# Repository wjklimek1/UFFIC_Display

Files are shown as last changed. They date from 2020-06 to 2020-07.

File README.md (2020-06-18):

# UFFIC_Display
Ultra Fast Inter Integrated Circuit Display

UFIIC Display converts I2C serial data to HD44780 display commands. It can be powered from 3.3V or 5V power source. In case of using 3.3V power source internal step-up converter is used to boost voltage to 5V required to power HD44780 itself. Converter is based on cheap STM32F030F4P6 microcontroller that can be programmed and debuged via SWD interface.

Project is at early stage of development now, code for UFIIC and Arduino library will be provided in the future.

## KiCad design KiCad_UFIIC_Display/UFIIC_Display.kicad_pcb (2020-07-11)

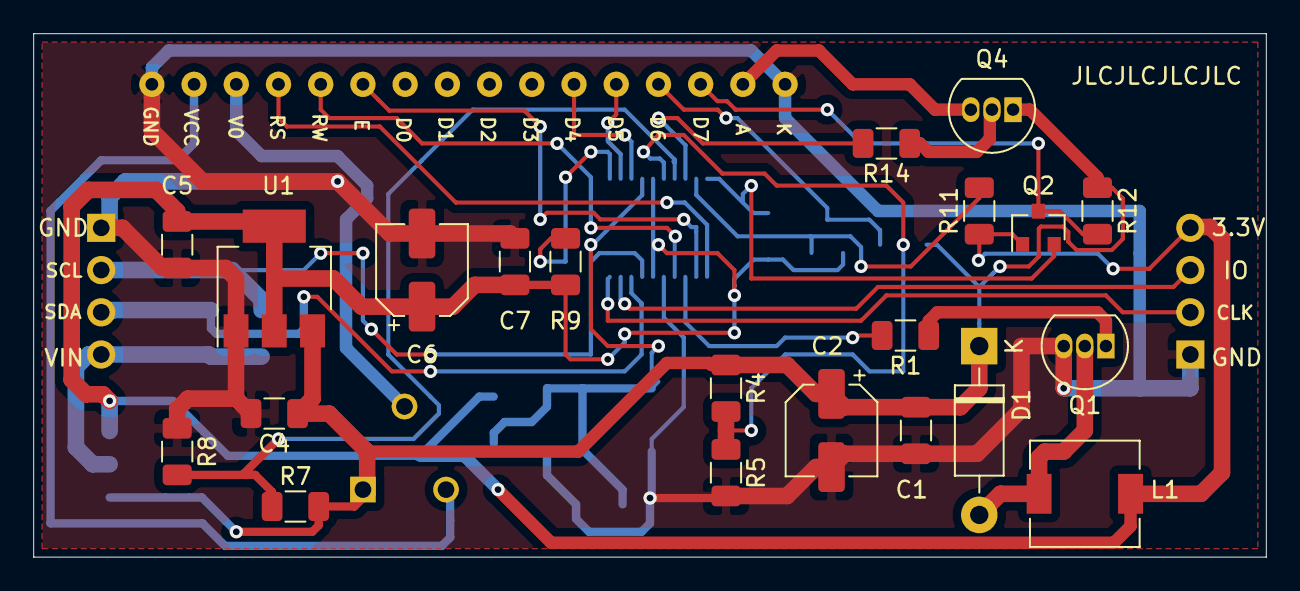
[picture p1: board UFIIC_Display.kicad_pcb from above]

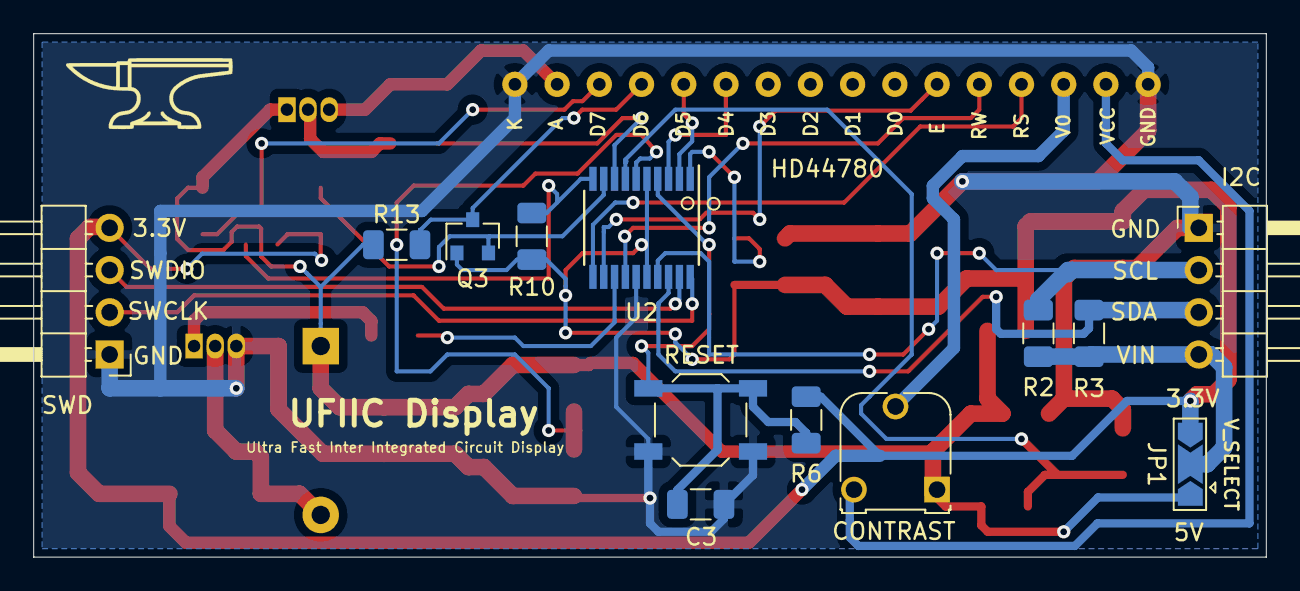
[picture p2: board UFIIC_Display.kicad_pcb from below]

Board: 2 copper layers, 74.2 x 31.5 mm, 35 parts (13 on the bottom side), 29 nets.

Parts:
C1, C3, C4, C5, C7: 100n; C_1206_3216Metric
C2, C6: 47u; CP_Elec_5x4.4
CONTRAST: 1K; Potentiometer_Runtron_RM-065_Vertical
D1: UF4007; D_DO-41_SOD81_P10.16mm_Horizontal
HD44780: HD44780
I2C: I2C; PinHeader_1x04_P2.54mm_Horizontal
JP1: VIN_SELECT; SolderJumper-3_P2.0mm_Open_TrianglePad1.0x1.5mm
L1: 100uH; L_6.3x6.3_H3
Q1: BC639; TO-92_Inline
Q2, Q3: BSS138; SOT-23
Q4: BC547; TO-92_Inline
R1, R6, R7, R8, R9, R14: 1K; R_1206_3216Metric
R2, R3: 4.7K; R_1206_3216Metric
R4: 3.3K; R_1206_3216Metric
R5: 820R; R_1206_3216Metric
R10, R11, R12, R13: 10K; R_1206_3216Metric
RESET: SW_Push; SW_SPST_TL3342
SWD: SWD; PinHeader_1x04_P2.54mm_Horizontal
U1: AMS1117-3.3; SOT-223-3_TabPin2
U2: STM32F030F4P6; TSSOP-20_4.4x6.5mm_P0.65mm

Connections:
+3V3: C5.1, C6.1, C7.1, JP1.3, L1.1, Q2.1, Q3.1, R6.1, R9.1, R10.1, R11.1, SWD.4, U1.2, U2.5, U2.16
/+5V: C1.1, C2.1, C4.1, CONTRAST.1, D1.1, JP1.1, Q4.1, R4.1, R7.2, R12.1, R13.1, U1.3
/ADC_DETECT: R7.1, R8.2, U2.7
/ADC_FEEDBACK: R4.2, R5.1, U2.6
/BACKLIGHT: R14.2, U2.8
/I2C1_SCL: I2C.2, R2.1, U2.17
/I2C1_SDA: I2C.3, R3.1, U2.18
/LCD_D4: HD44780.D4, U2.3
/LCD_D5: HD44780.D5, U2.2
/LCD_D6: Q3.2, R11.2, U2.9
/LCD_D7: Q2.2, R10.2, U2.10
/LCD_E: HD44780.E, U2.12
/LCD_RS: HD44780.RS, U2.11
/LCD_RW: HD44780.RW, U2.14
/PWM: R1.2, U2.13
/SWCLK: SWD.2, U2.20
/SWDIO: SWD.3, U2.19
/VIN: I2C.4, JP1.2, R2.2, R3.2
GND: C1.2, C2.2, C3.2, C4.2, C5.2, C6.2, C7.2, HD44780.GND, HD44780.K, I2C.1, Q1.3, R5.2, R8.1, RESET.1, SWD.1, U1.1, U2.15
unnamed: C3.1, R6.2, RESET.2, U2.4
unnamed: D1.2, L1.2, Q1.2
unnamed: Q1.1, R1.1
unnamed: HD44780.D7, Q2.3, R12.2
unnamed: HD44780.D6, Q3.3, R13.2
unnamed: Q4.2, R14.1
unnamed: HD44780.A, Q4.3
unnamed: R9.2, U2.1
unnamed: CONTRAST.2, HD44780.V0
unnamed: CONTRAST.3, HD44780.VCC

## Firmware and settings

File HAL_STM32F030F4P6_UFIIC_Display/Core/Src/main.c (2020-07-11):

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

/* Includes ------------------------------------------------------------------*/
#include "main.h"
#include "adc.h"
#include "dma.h"
#include "i2c.h"
#include "tim.h"
#include "gpio.h"

/* USER CODE BEGIN Includes */
#include "LCD_HD44780.h"
/* USER CODE END Includes */


/* USER CODE BEGIN PV */

// ADC data tab for DMA
// ADC_tab[0] = ADC_FEEDBACK, ADC_tab[1] = ADC_DETECT
uint32_t ADC_tab[2];

//PWM parameters - may need to be modified in final PCB
uint32_t PWM_Duty = 0;
uint32_t PWM_max = 100;
uint32_t PWM_min = 10;
uint16_t ADC_target = 770;  //target step-up voltage


/* USER CODE END PV */

void SystemClock_Config(void);
/* USER CODE BEGIN 0 */

//Timer overflow callback function - update step-up PWM duty in 1ms intervals
void HAL_TIM_PeriodElapsedCallback(TIM_HandleTypeDef *htim)
{
	if (htim->Instance == TIM16) {
		//Step-up converter logic
		if (ADC_tab[0] < ADC_target && PWM_Duty < PWM_max)
		{
			PWM_Duty++;
			TIM17->CCR1 = PWM_Duty;
		}
		if (ADC_tab[0] > ADC_target && PWM_Duty > PWM_min)
		{
			PWM_Duty--;
			TIM17->CCR1 = PWM_Duty;
		}
	}
}
/* USER CODE END 0 */

/**
  * @brief  The application entry point.
  * @retval int
  */
int main(void)
{
  /* MCU Configuration--------------------------------------------------------*/

  /* Reset of all peripherals, Initializes the Flash interface and the Systick. */
  HAL_Init();

  /* Configure the system clock */
  SystemClock_Config();

  /* Initialize all configured peripherals */
  MX_GPIO_Init();
  MX_DMA_Init();
  MX_ADC_Init();
  MX_I2C1_Init();
  MX_TIM17_Init();
  MX_TIM16_Init();
  MX_TIM14_Init();
  /* USER CODE BEGIN 2 */

  HAL_TIM_Base_Start_IT(&htim16);             //start timer16 - used to update step-up PWM in constant intervals
  HAL_ADCEx_Calibration_Start(&hadc);
  HAL_ADC_Start_DMA(&hadc, ADC_tab, 2);       //start ADC in DMA mode
  HAL_TIM_PWM_Start(&htim17, TIM_CHANNEL_1);  //start timer17 - generate PWM for step-up
  HAL_TIM_Base_Start(&htim14);                //start timer14 - base for microseconds delay function

  LCD_Init();

  /* USER CODE END 2 */

  /* Infinite loop */
  /* USER CODE BEGIN WHILE */
	while (1)
	{
		LCD_Cls();
		LCD_Locate(0, 0);
		LCD_String("UFIIC Display");
		HAL_Delay(2000);
		LCD_Locate(0, 1);
		LCD_String("First test");
		HAL_Delay(2000);
		LCD_Cls();
		HAL_Delay(2000);
		/* USER CODE END WHILE */

		/* USER CODE BEGIN 3 */
	}
  /* USER CODE END 3 */
}

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


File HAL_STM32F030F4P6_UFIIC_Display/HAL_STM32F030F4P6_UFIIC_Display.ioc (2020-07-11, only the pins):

Mcu.UserName=STM32F030F4Px
PA0.GPIO_Label=ADC_FEEDBACK
PA0.Signal=ADC_IN0
PA1.GPIO_Label=ADC_DETECT
PA1.Signal=ADC_IN1
PA10.Signal=I2C1_SDA
PA13.Signal=SYS_SWDIO
PA14.Signal=SYS_SWCLK
PA2.GPIO_Label=BACKLIGHT
PA2.Signal=GPIO_Output
PA3.GPIO_Label=LCD_D6
PA3.Signal=GPIO_Output
PA4.GPIO_Label=LCD_D7
PA4.Signal=GPIO_Output
PA5.GPIO_Label=LCD_RS
PA5.Signal=GPIO_Output
PA6.GPIO_Label=LCD_E
PA6.Signal=GPIO_Output
PA7.GPIO_Label=PWM
PA7.Signal=S_TIM17_CH1
PA9.Signal=I2C1_SCL
PB1.GPIO_Label=LCD_RW
PB1.Signal=GPIO_Output
PF0-OSC_IN.GPIO_Label=LCD_D5
PF0-OSC_IN.Signal=GPIO_Output
PF1-OSC_OUT.GPIO_Label=LCD_D4
PF1-OSC_OUT.Signal=GPIO_Output

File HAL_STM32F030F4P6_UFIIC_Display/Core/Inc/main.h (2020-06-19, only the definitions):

#define LCD_D5_Pin GPIO_PIN_0
#define LCD_D5_GPIO_Port GPIOF
#define LCD_D4_Pin GPIO_PIN_1
#define LCD_D4_GPIO_Port GPIOF
#define ADC_FEEDBACK_Pin GPIO_PIN_0
#define ADC_FEEDBACK_GPIO_Port GPIOA
#define ADC_DETECT_Pin GPIO_PIN_1
#define ADC_DETECT_GPIO_Port GPIOA
#define BACKLIGHT_Pin GPIO_PIN_2
#define BACKLIGHT_GPIO_Port GPIOA
#define LCD_D6_Pin GPIO_PIN_3
#define LCD_D6_GPIO_Port GPIOA
#define LCD_D7_Pin GPIO_PIN_4
#define LCD_D7_GPIO_Port GPIOA
#define LCD_RS_Pin GPIO_PIN_5
#define LCD_RS_GPIO_Port GPIOA
#define LCD_E_Pin GPIO_PIN_6
#define LCD_E_GPIO_Port GPIOA
#define PWM_Pin GPIO_PIN_7
#define PWM_GPIO_Port GPIOA
#define LCD_RW_Pin GPIO_PIN_1
#define LCD_RW_GPIO_Port GPIOB

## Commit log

2020-06-18 KiCad schematic and PCB
    + Added KiCad schematic and PCB
    + Added .gitignore file
    + Updated readme.md file
    [UFIIC_Display.kicad_pcb, UFIIC_Display.sch]
2020-06-19 ADC read by DMA
    + Initial configuration in CubeIDE
    + ADC read by DMA
    + timer initialization
2020-06-20 Added step-up converter logic
    + Step-up voltage converter logic added to timer16 interrupt handler
2020-07-11 Backlight powered by 5V step up
    + backlight is powered by 5V step-up
    + removed unnecessary KiCad files
    + updated .gitignore
    [UFIIC_Display.kicad_pcb, UFIIC_Display.sch]

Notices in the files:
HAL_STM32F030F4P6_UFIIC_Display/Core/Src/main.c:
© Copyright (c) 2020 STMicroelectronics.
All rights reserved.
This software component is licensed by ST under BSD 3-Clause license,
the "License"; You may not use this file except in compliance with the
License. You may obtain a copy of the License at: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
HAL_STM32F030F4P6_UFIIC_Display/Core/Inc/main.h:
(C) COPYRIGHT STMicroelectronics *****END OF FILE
